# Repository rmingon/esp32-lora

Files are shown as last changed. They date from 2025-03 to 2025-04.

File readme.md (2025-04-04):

# ESP32 LoRa Nunchuck System

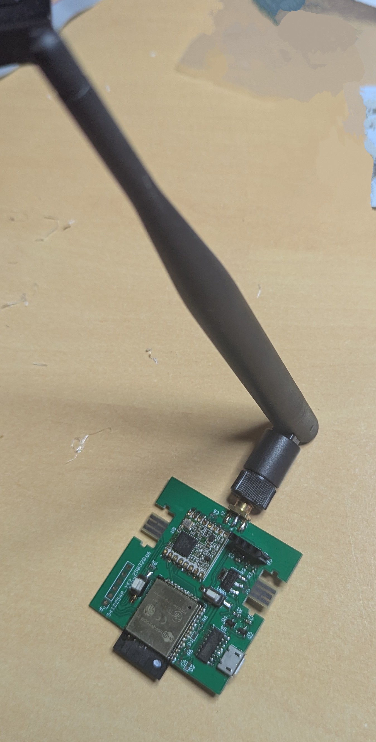
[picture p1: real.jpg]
real


## Overview
This project integrates an ESP32 microcontroller with LoRa communication and two Nunchuck connectors, enabling remote control and data transmission applications. The system is designed for long-range communication while leveraging the Wii Nunchuck controllers for user input.

## Features
- **ESP32**: Wi-Fi and Bluetooth-enabled microcontroller
- **LoRa Module**: Long-range communication support
- **Dual Nunchuck Connectors on Separate I²C Buses**
- **Powered via USB**: No LiPo battery required

## Hardware Requirements
- ESP32 development board
- LoRa module (RFM95W-868S2)
- Two Wii Nunchuck controllers
- Nunchuck connectors
- USB power source
- Jumper wires & breadboard (or custom PCB)

## Wiring Diagram (Based on Schematic)
| ESP32 Pin | LoRa Pin | Nunchuck 1 Pin | Nunchuck 2 Pin |
|---|---|---|---|
| 3.3V | VCC | VCC | VCC |
| GND | GND | GND | GND |
| GPIO5 | NSS | - | - |
| GPIO18 | SCK | - | - |
| GPIO19 | MISO | - | - |
| GPIO23 | MOSI | - | - |
| GPIO26 | DIO0 | - | - |
| GPIO21 | - | SDA (I²C 1) | - |
| GPIO22 | - | SCL (I²C 1) | - |
| GPIO25 | - | - | SDA (I²C 2) |
| GPIO33 | - | - | SCL (I²C 2) |

## Software Requirements
- Arduino IDE / PlatformIO
- ESP32 board package
- LoRa library (e.g., `RadioHead` or `LoRa.h`)
- Nunchuck library (e.g., `Wire.h`, `ArduinoNunchuk.h`)

## Usage
1. Connect the hardware components as per the wiring diagram.
2. Power up the ESP32 via USB.
3. Use the Nunchuck controllers to send data via LoRa.
4. Monitor data via serial output.

## Example Code
```cpp
#include <Wire.h>
#include <ArduinoNunchuk.h>
#include <LoRa.h>

TwoWire I2C_1 = TwoWire(0);
TwoWire I2C_2 = TwoWire(1);

ArduinoNunchuk nunchuk1;
ArduinoNunchuk nunchuk2;

void setup() {
    Serial.begin(115200);
    I2C_1.begin(21, 22); // SDA1 = GPIO21, SCL1 = GPIO22
    I2C_2.begin(25, 33); // SDA2 = GPIO25, SCL2 = GPIO33
    
    nunchuk1.init(I2C_1);
    nunchuk2.init(I2C_2);
    
    LoRa.begin(915E6);
}

void loop() {
    nunchuk1.update();
    nunchuk2.update();
    
    LoRa.beginPacket();
    LoRa.print(nunchuk1.analogX);
    LoRa.print(",");
    LoRa.print(nunchuk2.analogX);
    LoRa.endPacket();
    
    delay(100);
}
```

## Contributing
Feel free to submit issues or pull requests for improvements and bug fixes.

---
Happy coding! 🚀

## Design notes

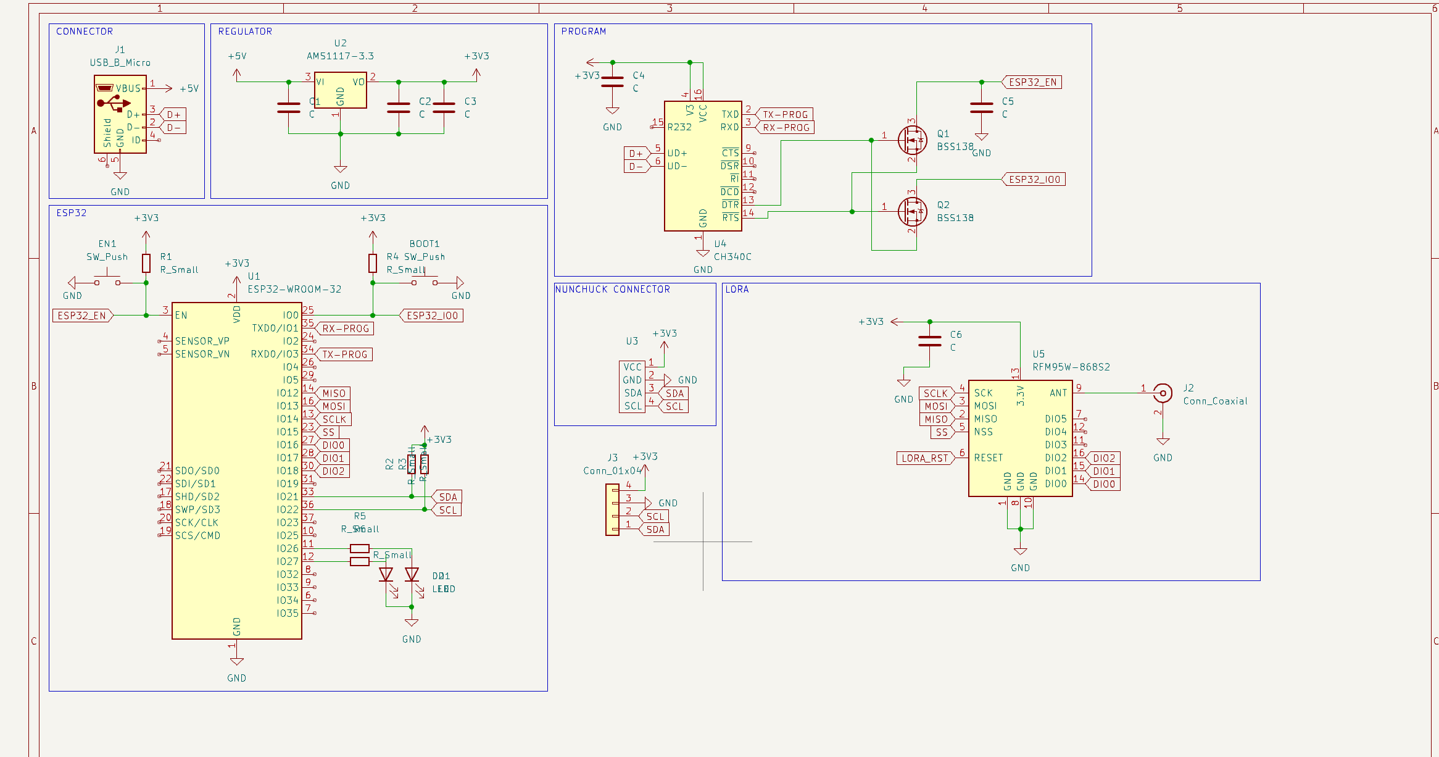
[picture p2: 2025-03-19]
schematic.png

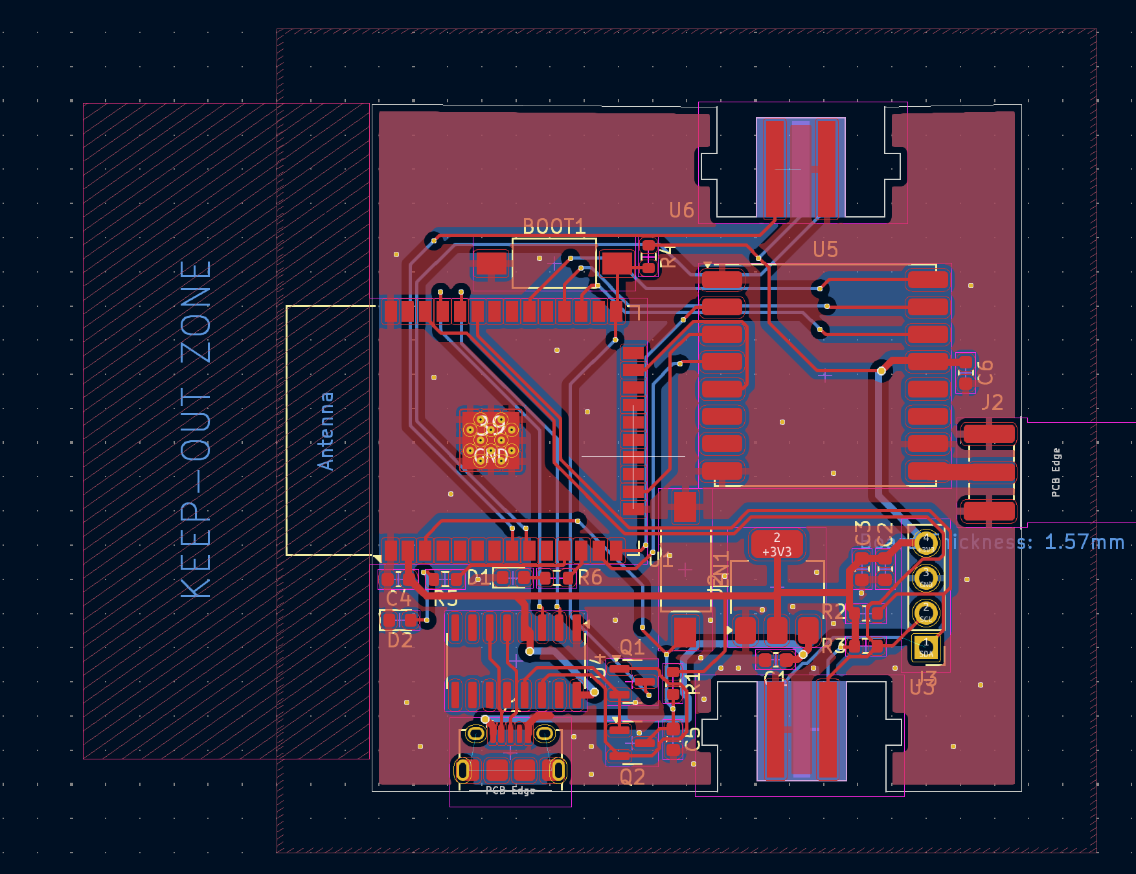
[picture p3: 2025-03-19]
pcb.png

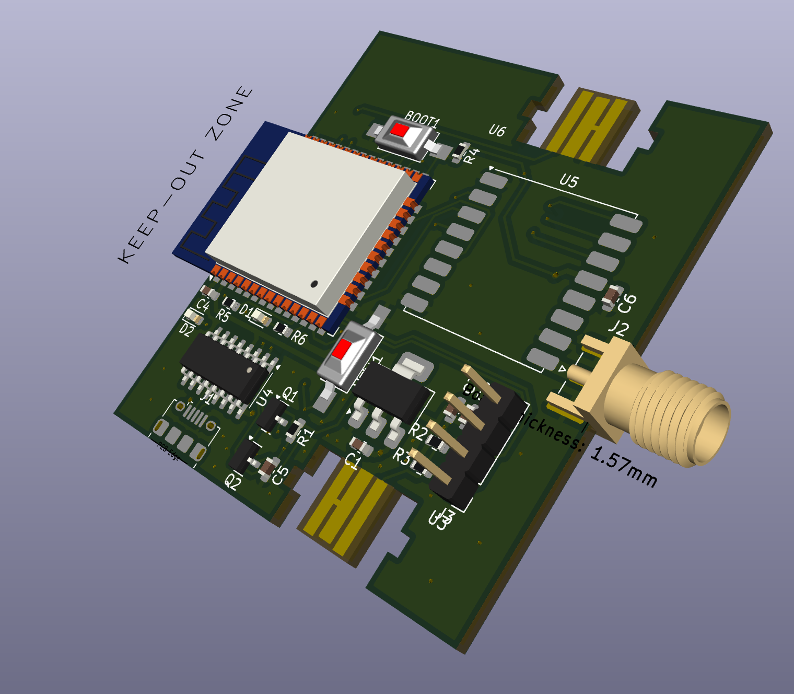
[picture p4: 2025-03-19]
3d.png

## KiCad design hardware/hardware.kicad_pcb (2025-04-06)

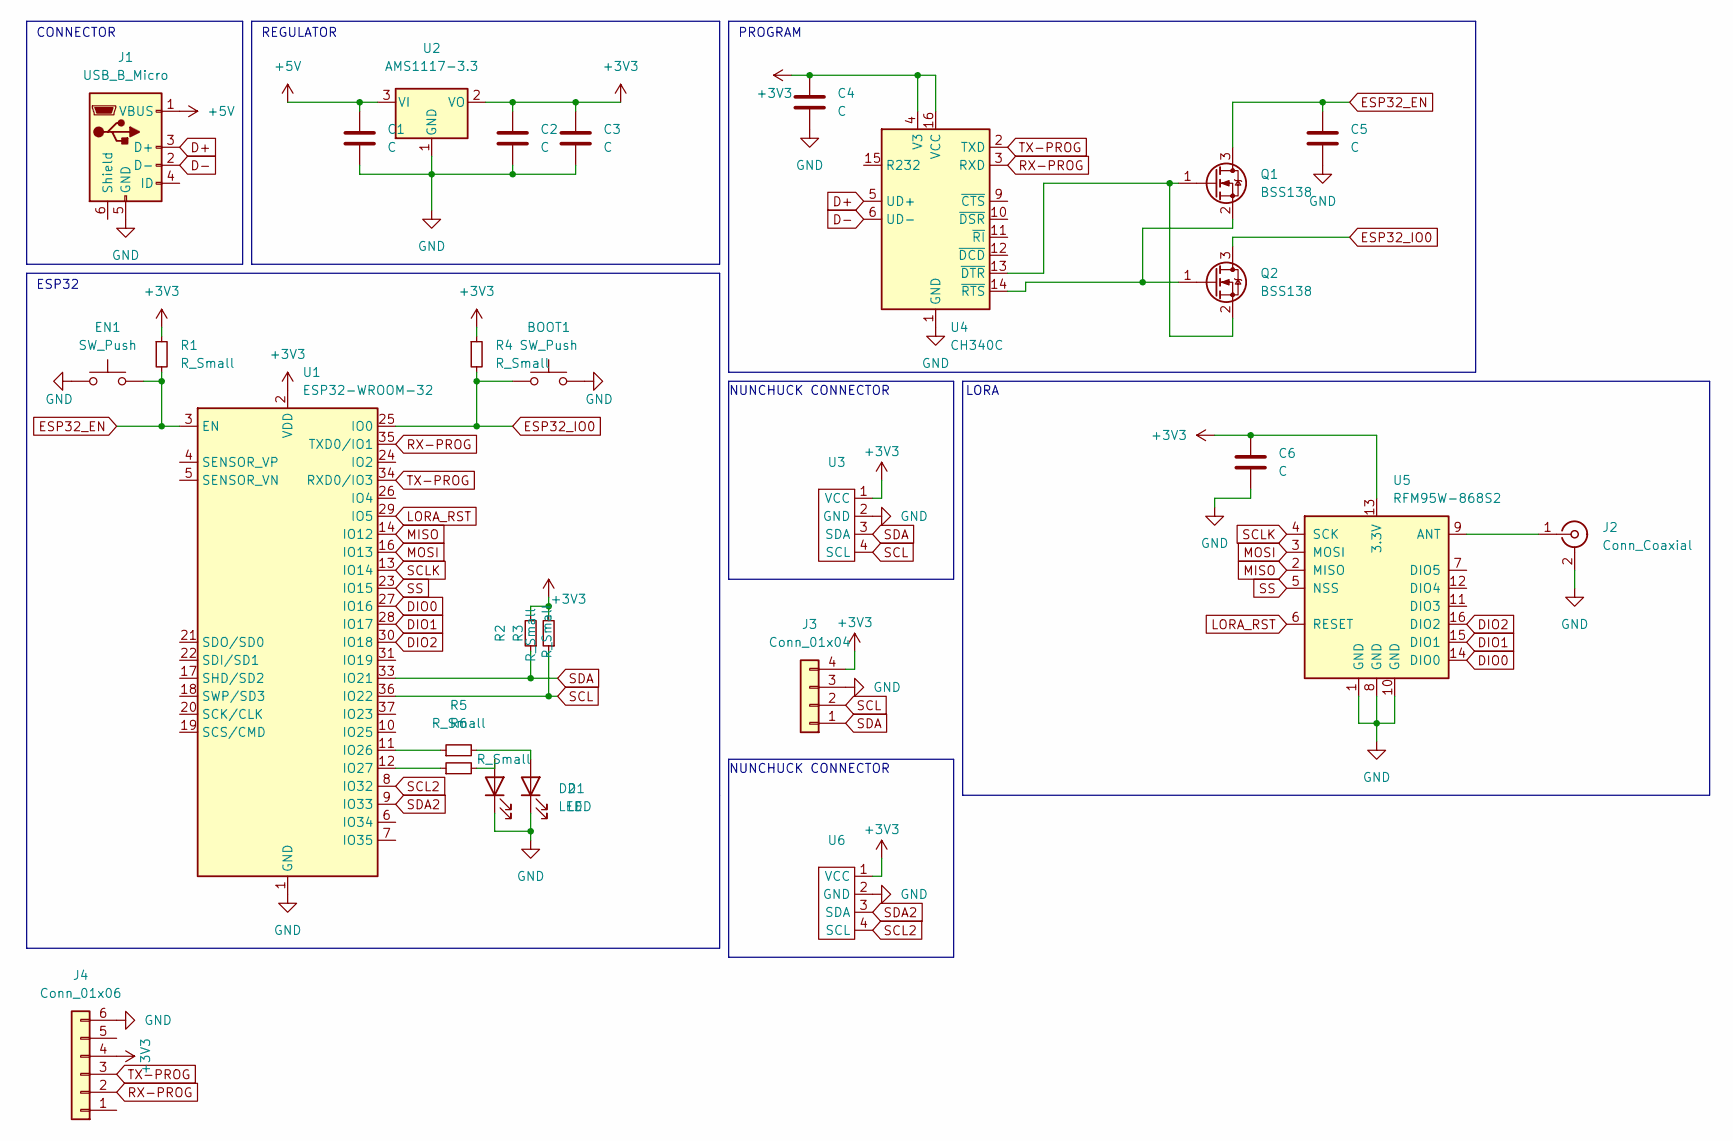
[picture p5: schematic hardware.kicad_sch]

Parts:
BOOT1: SW_Push; SW_SPST_FSMSM
C1, C2, C3, C4, C5, C6: C; C_0603_1608Metric
D1, D2: LED; LED_0603_1608Metric
EN1: SW_Push; SW_SPST_FSMSM
J1: USB_B_Micro; USB_Micro-B_Amphenol_10118194_Horizontal
J2: Conn_Coaxial; SMA_Samtec_SMA-J-P-H-ST-EM1_EdgeMount
J3: Conn_01x04; PinHeader_1x04_P2.54mm_Vertical
J4: Conn_01x06; PinHeader_1x06_P2.54mm_Vertical
Q1, Q2: BSS138; SOT-23
R1, R2, R3, R4, R5, R6: R_Small; R_0603_1608Metric
U1: ESP32-WROOM-32
U2: AMS1117-3.3; SOT-223-3_TabPin2
U3, U6: nunchuck
U4: CH340C; SOIC-16_3.9x9.9mm_P1.27mm
U5: RFM95W-868S2; HOPERF_RFM9XW_SMD

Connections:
+3V3: C2.1, C3.1, C4.1, C6.1, J3.4, J4.4, R1.1, R2.2, R3.2, R4.1, U1.2 (VDD), U2.2 (VO), U3.1 (VCC), U4.4 (V3), U4.16 (VCC), U5.13 (3.3V), U6.1 (VCC)
+5V: C1.1, J1.1 (VBUS), U2.3 (VI)
D+: J1.3 (D+), U4.5 (UD+)
D-: J1.2 (D-), U4.6 (UD-)
DIO0: U1.27 (IO16), U5.14 (DIO0)
DIO1: U1.28 (IO17), U5.15 (DIO1)
DIO2: U1.30 (IO18), U5.16 (DIO2)
ESP32_EN: C5.1, EN1.2, Q1.3 (D), R1.2, U1.3 (EN)
ESP32_IO0: BOOT1.1, Q2.3 (D), R4.2, U1.25 (IO0)
GND: BOOT1.2, C1.2, C2.2, C3.2, C4.2, C5.2, C6.2, D1.1 (K), D2.1 (K), EN1.1, J1.5 (GND), J2.2 (Ext), J3.3, J4.6, U1.1 (GND), U1.15 (GND), U1.38 (GND), U1.39 (GND), U2.1 (GND), U3.2 (GND), U4.1 (GND), U5.1 (GND), U5.8 (GND), U5.10 (GND), U6.2 (GND)
LORA_RST: U1.29 (IO5), U5.6 (RESET)
MISO: U1.14 (IO12), U5.2 (MISO)
MOSI: U1.16 (IO13), U5.3 (MOSI)
unnamed: D1.2 (A), R6.2
unnamed: D2.2 (A), R5.2
unnamed: J2.1 (In), U5.9 (ANT)
unnamed: Q1.1 (G), Q2.2 (S), U4.13 (~DTR)
unnamed: Q1.2 (S), Q2.1 (G), U4.14 (~RTS)
unnamed: R5.1, U1.11 (IO26)
unnamed: R6.1, U1.12 (IO27)
RX-PROG: J4.2, U1.35 (TXD0/IO1), U4.3 (RXD)
SCL: J3.2, R3.1, U1.36 (IO22), U3.4 (SCL)
SCL2: U1.8 (IO32), U6.4 (SCL)
SCLK: U1.13 (IO14), U5.4 (SCK)
SDA: J3.1, R2.1, U1.33 (IO21), U3.3 (SDA)
SDA2: U1.9 (IO33), U6.3 (SDA)
SS: U1.23 (IO15), U5.5 (NSS)
TX-PROG: J4.3, U1.34 (RXD0/IO3), U4.2 (TXD)

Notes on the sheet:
CONNECTOR
ESP32
PROGRAM
LORA
REGULATOR
NUNCHUCK CONNECTOR

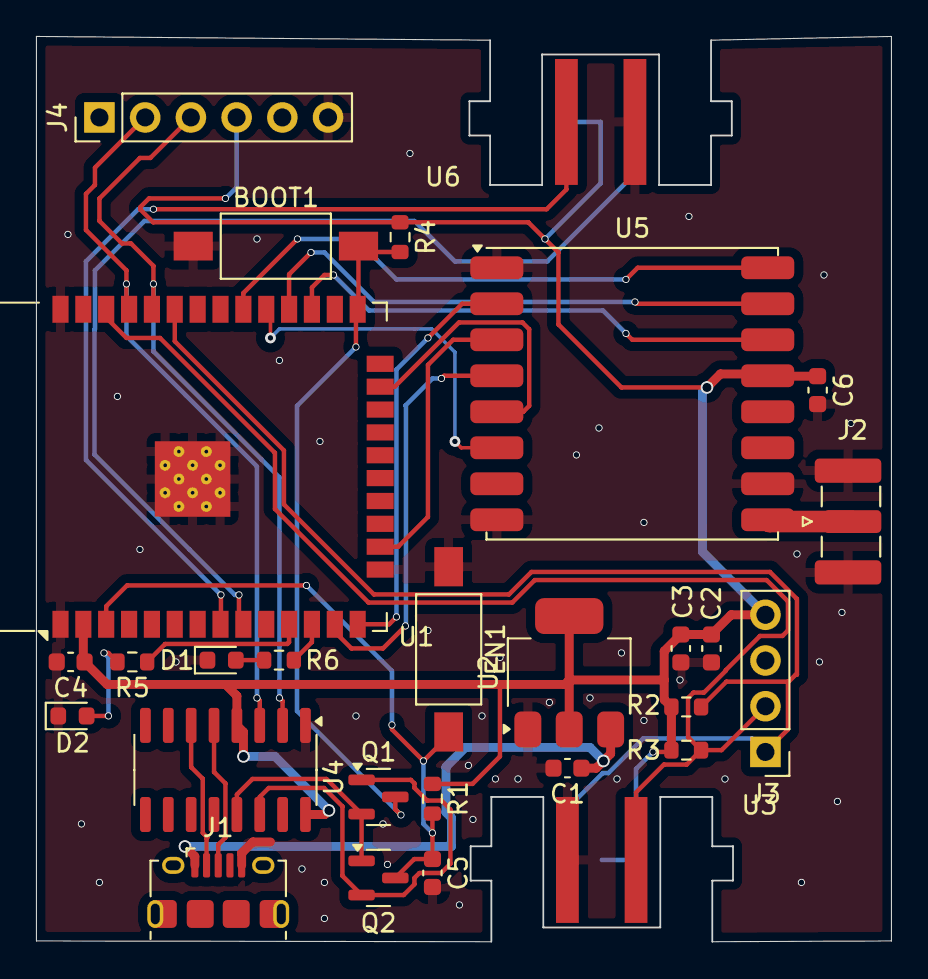
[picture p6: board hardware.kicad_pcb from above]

Board: 2 copper layers, 47.5 x 50.3 mm, 28 parts (0 on the bottom side), 28 nets.

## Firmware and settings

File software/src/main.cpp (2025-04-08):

#include <WiiChuck.h>
#include <Wire.h>
Accessory nunchuck1;

#include <SPI.h>
#include <LoRa.h>
SPIClass spi;

#include <Adafruit_GFX.h>
#include <Adafruit_SH1106.h>

#include <AsyncTCP.h>
#include <WiFi.h>
#include <ESPAsyncWebServer.h>

// OLED display size
#define SCREEN_WIDTH 128
#define SCREEN_HEIGHT 64

Adafruit_SH1106 display(0);

void loraSend(byte*, size_t);
void onReceive(int);
void drawRoll(int);
void drawPitch(int);

const int numDoubles = 5;
const int doubleSize = sizeof(double);
byte buffer[numDoubles * doubleSize];
double receivedValues[numDoubles];

double speed = 0;
double lon = 0;
double lat = 0;

double data[5] = {0.0, 0.0, 0.0, 0.0, 0.0};

static AsyncWebServer server(80);
static AsyncWebSocket ws("/ws");

void initWiFi() {
  WiFi.mode(WIFI_STA);
  WiFi.begin("ssid", "passsword");
  Serial.print("Connecting to WiFi ..");
  while (WiFi.status() != WL_CONNECTED) {
    Serial.print('.');
    delay(1000);
  }
  Serial.println(WiFi.localIP());
}

void setup() {
	Serial.begin(115200);
  Wire.begin(21,22);
  initWiFi();
  server.begin();
  nunchuck1.begin();
  if (nunchuck1.type == Unknown) {
		nunchuck1.type = NUNCHUCK;
	}

  spi.begin(14, 12, 13); // SCK, MISO, MOSI, SS
  LoRa.setSPI(spi);
  LoRa.setPins(15, 26, 16);
  if (!LoRa.begin(868E6)) {
      Serial.println("LoRa init failed. Check your connections.");
      while (true);                       // if failed, do nothing
  }
  LoRa.setSpreadingFactor(7);
  LoRa.setSignalBandwidth(250E3);
  LoRa.setTxPower(20);
  LoRa.setSyncWord(0xF3);
  LoRa.receive();

  ws.onEvent([](AsyncWebSocket *server, AsyncWebSocketClient *client, AwsEventType type, void *arg, uint8_t *data, size_t len) {
    (void)len;

    if (type == WS_EVT_CONNECT) {
      ws.textAll("new client connected");
      Serial.println("ws connect");
      client->setCloseClientOnQueueFull(false);
      client->ping();

    } else if (type == WS_EVT_DISCONNECT) {
      ws.textAll("client disconnected");
      Serial.println("ws disconnect");

    } else if (type == WS_EVT_ERROR) {
      Serial.println("ws error");

    } else if (type == WS_EVT_PONG) {
      Serial.println("ws pong");

    } else if (type == WS_EVT_DATA) {
      AwsFrameInfo *info = (AwsFrameInfo *)arg;
      Serial.printf("index: %" PRIu64 ", len: %" PRIu64 ", final: %" PRIu8 ", opcode: %" PRIu8 "\n", info->index, info->len, info->final, info->opcode);
      String msg = "";
      if (info->final && info->index == 0 && info->len == len) {
        if (info->opcode == WS_TEXT) {
          data[len] = 0;
          Serial.printf("ws text: %s\n", (char *)data);
        }
      }
    }
  });

  // shows how to prevent a third WS client to connect
  server.addHandler(&ws).addMiddleware([](AsyncWebServerRequest *request, ArMiddlewareNext next) {
    // ws.count() is the current count of WS clients: this one is trying to upgrade its HTTP connection
    if (ws.count() > 1) {
      // if we have 2 clients or more, prevent the next one to connect
      request->send(503, "text/plain", "Server is busy");
    } else {
      // process next middleware and at the end the handler
      next();
    }
  });

  server.addHandler(&ws);

  server.begin();

  Serial.println("LoRa Initializing OK!");

  display.begin();
  display.clearDisplay(); 
  display.setTextSize(1); 
  display.setTextColor(WHITE);
}

void drawRoll(int degree) {
  display.drawLine(30, 20 + degree, display.width() - 38, 20 - degree,  WHITE);
}

void drawRollPlane(int degree) {
  display.drawLine(0, 20 + degree, display.width() - 8, 20 - degree,  WHITE);
}

void drawPitch(int degree) {
  display.drawLine(120, display.height() / 2 + degree, display.width() , display.height() / 2 + degree,  WHITE);
}

void drawPitchPlane(int degree) {
  display.drawLine(120, display.height() / 2 + degree, display.width() , display.height() / 2 + degree,  WHITE);
}

void loop() {
  display.clearDisplay(); 
	nunchuck1.readData();

  byte cmd = 0b00000000;

  int centerX = 60;
  int centerY = 20;
  int radius = 12;

  display.drawCircle(centerX, centerY, radius, WHITE);
  display.fillRect(centerX - radius , centerY, radius * 3, radius + 2, BLACK);

  display.drawLine(120, 0, 120 , display.height(),  WHITE);

  int roll = (nunchuck1.getAccelX() - 475) / 10;
  int pitch = (nunchuck1.getAccelY() - 475) / 9;

  drawRoll(roll);
  drawPitch(pitch);
  drawRollPlane(int(trunc(receivedValues[4])));
  drawPitchPlane(int(trunc(receivedValues[3])));

  display.setCursor(0, 0);
  if(nunchuck1.getButtonC()) {
    cmd |= 0b00000001;
    display.print("C");
  } else {
    display.print(" ");
  }

  display.setCursor(8, 0);
  if(nunchuck1.getButtonZ()) {
    cmd |= 0b00000010;
    display.print("Z");
  } else {
    display.print(" ");
  }


  display.setCursor(40, 0);
  display.println(WiFi.localIP());
  
  byte data[] = {
    cmd,
    (byte)(roll + 127),
    (byte)(pitch + 127)
  };

  loraSend(data, sizeof(data));

  onReceive(LoRa.parsePacket());

  display.setCursor(0, 48);
  display.print("RSSI ");
  display.print(LoRa.packetRssi());
  display.print("KMH ");
  display.print(receivedValues[2], 2);

  display.setCursor(0, 56);
  display.print("LAT ");
  display.print(receivedValues[0], 4);
  display.print("LON ");
  display.print(receivedValues[1], 4);
  display.display();
  delay(50);
}

void decodeLora(byte* data, size_t length) {

}

void onReceive(int packetSize) {
  if (packetSize == 0) return;

  if (packetSize == numDoubles * doubleSize) {
    for (int i = 0; i < packetSize; i++) {
      buffer[i] = LoRa.read();
    }

    // Unpack bytes back into doubles
    for (int i = 0; i < numDoubles; i++) {
        memcpy(&receivedValues[i], buffer + i * doubleSize, doubleSize);
    }

    // Print received doubles
    Serial.println("Received values:");
    for (int i = 0; i < numDoubles; i++) {
      Serial.print("Double ");
      Serial.print(i);
      Serial.print(": ");
      Serial.println(receivedValues[i], 6);
    }
    Serial.println("-----------");
  }
  Serial.print(" || RSSI: ");
  Serial.println(LoRa.packetRssi());
  Serial.println();
}

void loraSend(byte* data, size_t length) {
  LoRa.beginPacket();
  LoRa.write(data, length);
  LoRa.endPacket();
  LoRa.receive();
}

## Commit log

2025-03-18 add schematic components
    [hardware.kicad_pcb, hardware.kicad_sch]
2025-03-18 add nunchuck footprint
    [hardware.kicad_sch]
2025-03-18 place pcb components
    [hardware.kicad_pcb]
2025-03-19 lora wiring + pcb wiring
    [hardware.kicad_pcb, hardware.kicad_sch]
2025-03-19 invert i2c screen wiring
    [hardware.kicad_pcb, hardware.kicad_sch]
2025-03-19 add second nunchuck connector and pcb wiring
    [hardware.kicad_pcb, hardware.kicad_sch]
2025-03-19 add ftdi pin and wiring to esp
    [hardware.kicad_pcb, hardware.kicad_sch]
2025-04-06 fix i2c wiring and lora rst
    [hardware.kicad_pcb, hardware.kicad_sch]
2025-04-06 add i2c screen and nunchuck move on screen
2025-04-08 add ws server
    [hardware-B_Cu.gbl]
